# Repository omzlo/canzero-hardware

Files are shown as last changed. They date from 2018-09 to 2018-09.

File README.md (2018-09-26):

# Canzero Hardware

This repository contains the design files and schematics of the Omzlo CANZERO, an Arduino-compatible CAN-bus node.

See: http://omzlo.com/canzero

This work is licensed under the [Creative Commons Attribution-ShareAlike 4.0 International Public License][1].

[1]: https://creativecommons.org/licenses/by-sa/4.0/

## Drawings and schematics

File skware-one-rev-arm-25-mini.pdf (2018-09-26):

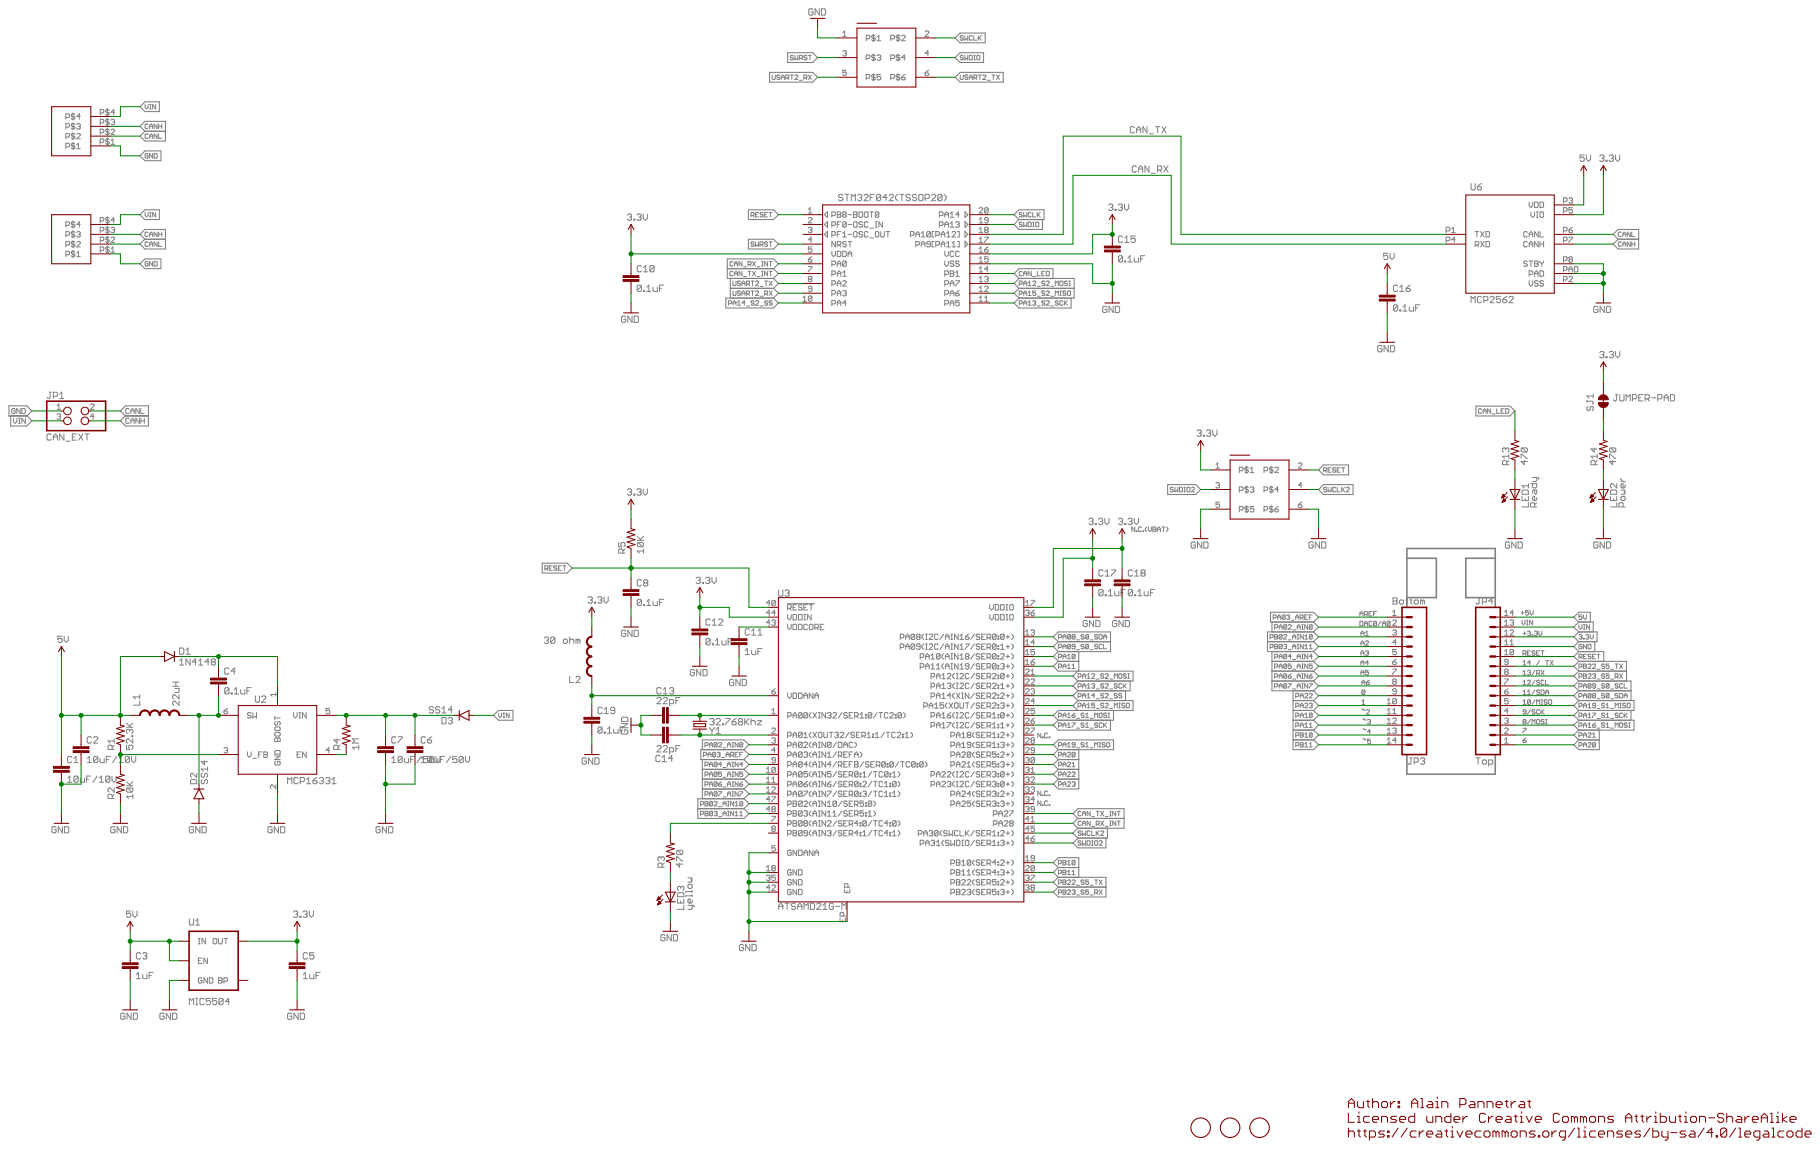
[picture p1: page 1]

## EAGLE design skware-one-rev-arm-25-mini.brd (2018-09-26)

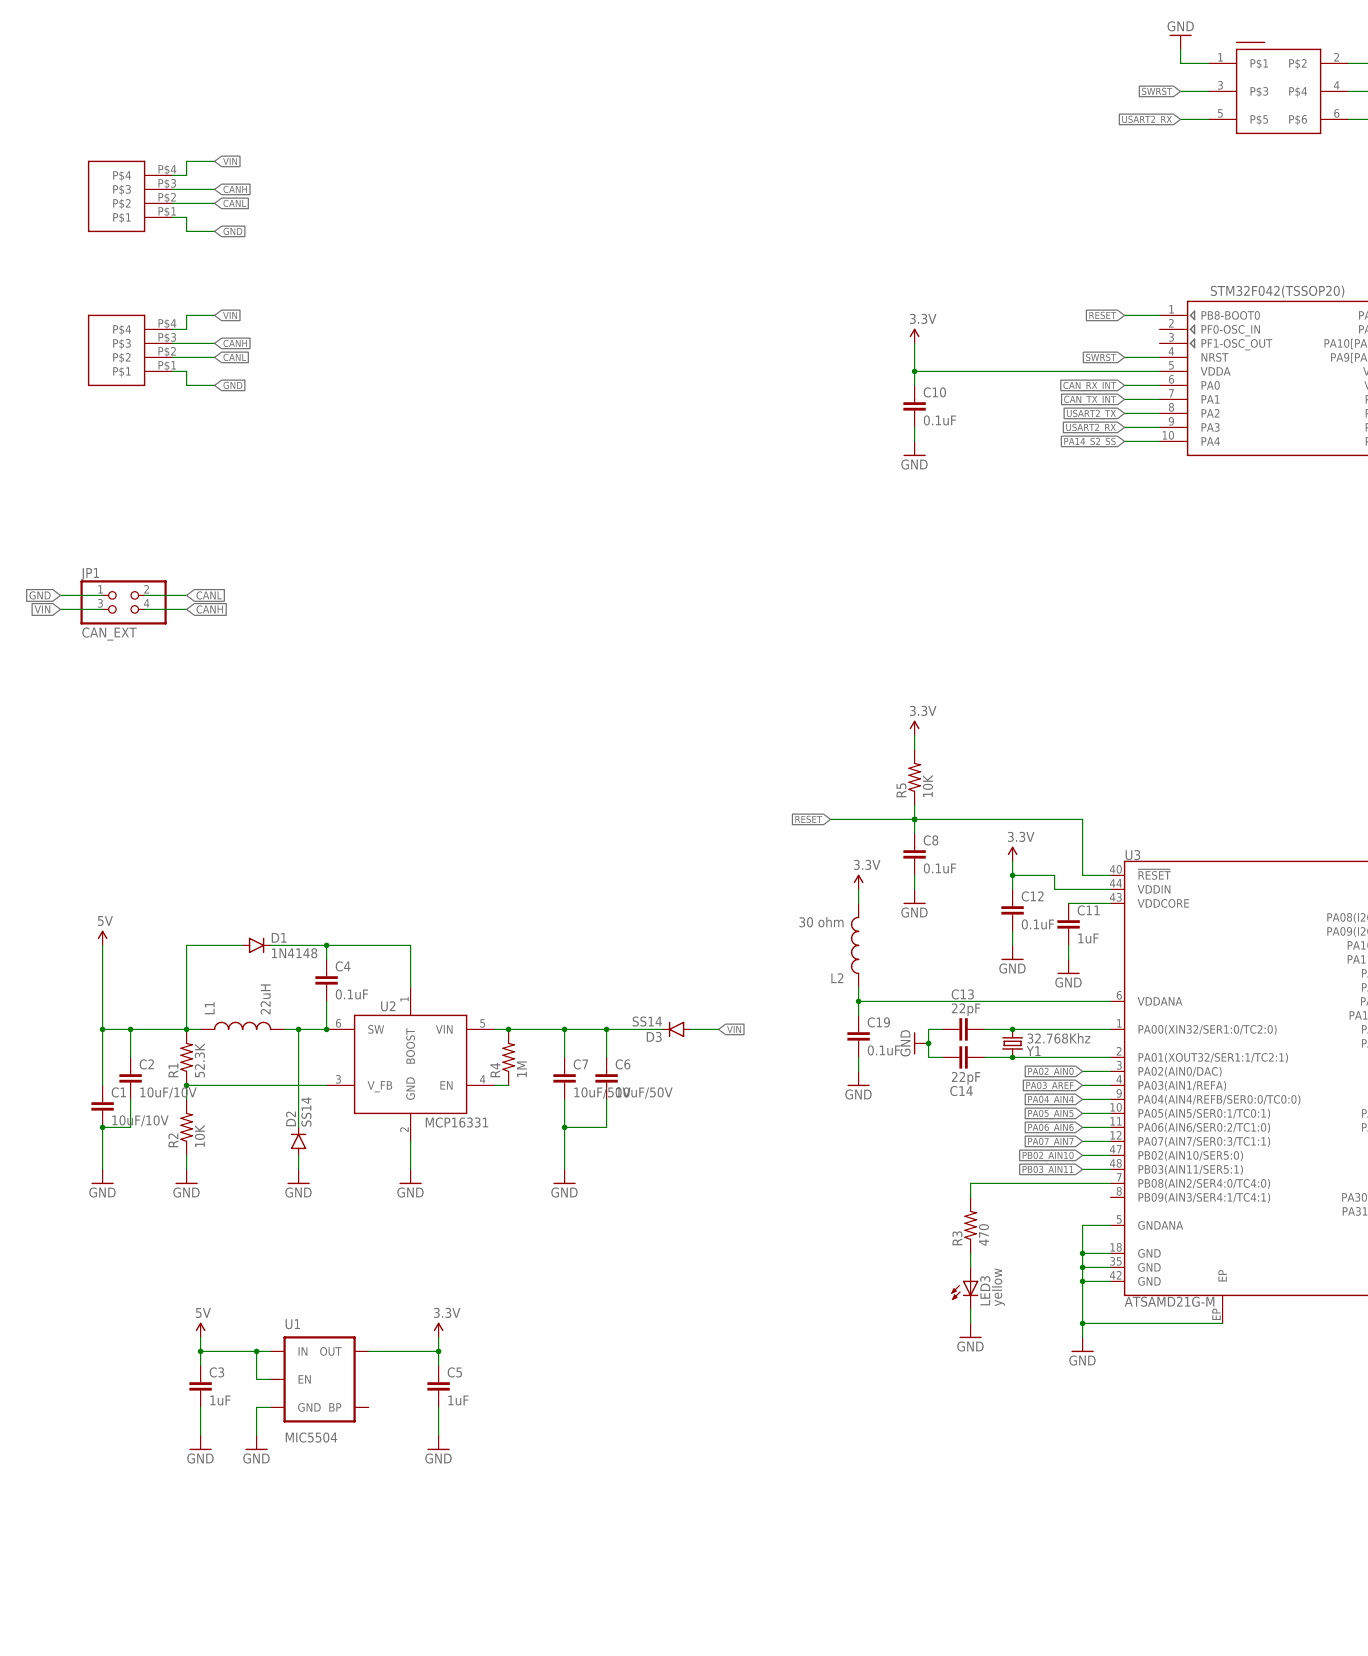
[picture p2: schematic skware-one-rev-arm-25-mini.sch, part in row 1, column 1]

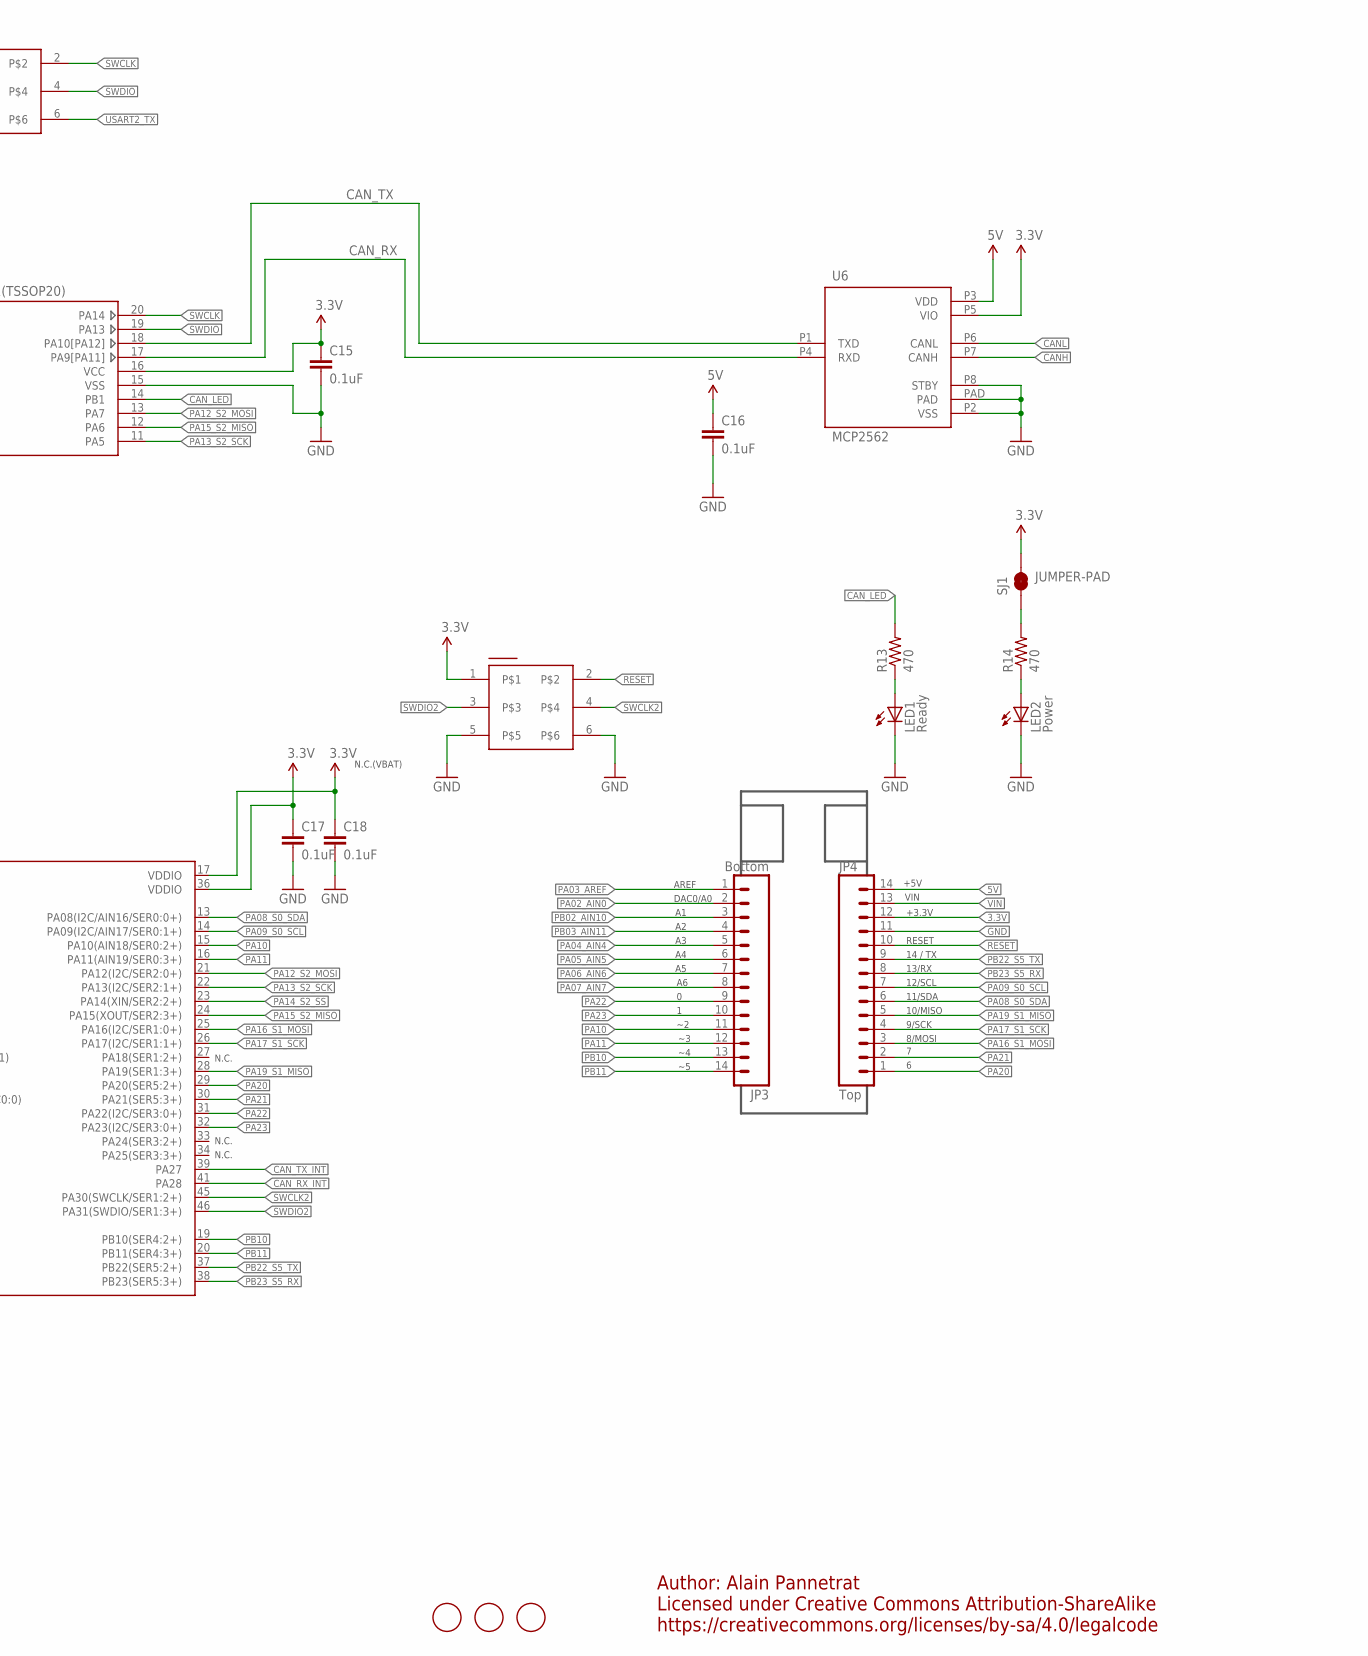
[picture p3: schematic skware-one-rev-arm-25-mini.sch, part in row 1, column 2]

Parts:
C1, C2: 10uF/10V; 0805
C3, C5, C11: 1uF; 0805
C4, C8, C10, C12, C15, C16, C17, C18, C19: 0.1uF; 0603-CAP
C6, C7: 10uF/50V; 1206
C13, C14: 22pF; 0805
D1: 1N4148; SOD-323
D2, D3: SS14; SMA-DIODE_ALT
JP1: CAN_EXT; 2X02
JP3: Bottom; 1X14
JP4: Top; 1X14
L1: 22uH; SRN6045
L2: 30 ohm; 0603
LED1: Ready; SML0805
LED2: Power; SML0805
LED3: yellow; SML0805
R1: 52.3K; 0805
R2, R5: 10K; 0805
R3, R13, R14: 470; 0603-RES
R4: 1M; 0805
SJ1: JUMPER-PAD; PAD-JUMPER-2-NC_BY_TRACE_YES_SILK
U1: MIC5504; SOT23-5
U2: MCP16331; SOT23-6
U3: ATSAMD21G-M; QFN-48
U4: STM32F042(TSSOP20); TSSOP20
U6: MCP2562; DFN3X3
U$1, U$3: M04-PLUG-3.5
U$4, U$5: 3X2-SMT-PROG; 2X3-SMT-HEAD
U$6, U$7, U$8: FIDUCIAL; FIDUCIAL_1MM
Y1: 32.768Khz; CRYSTAL-SMD-3.2X1.5MM

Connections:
3.3V: C5.1, C10.1, C12.1, C15.1, C17.1, C18.1, JP4.12, L2.2, R5.2, SJ1.2, U1.5 (OUT), U3.17 (VDDIO), U3.36 (VDDIO), U3.44 (VDDIN), U4.5 (VDDA), U4.16 (VCC), U6.P5 (VIO), U$4.1
5V: C1.1, C2.1, C3.1, C16.1, D1.A, JP4.14, L1.1, R1.2, U1.1 (IN), U1.3 (EN), U6.P3 (VDD)
A1: R3.2, U3.7 (PB08(AIN2/SER4:0/TC4:0))
CANH: JP1.4, U6.P7 (CANH), U$1.P$3, U$3.P$3
CANL: JP1.2, U6.P6 (CANL), U$1.P$2, U$3.P$2
CAN_LED: R13.2, U4.14 (PB1)
CAN_RX: U4.17 (PA9[PA11]), U6.P4 (RXD)
CAN_RX_INT: U3.41 (PA28), U4.6 (PA0)
CAN_TX: U4.18 (PA10[PA12]), U6.P1 (TXD)
CAN_TX_INT: U3.39 (PA27), U4.7 (PA1)
GND: C1.2, C2.2, C3.2, C5.2, C6.2, C7.2, C8.2, C10.2, C11.2, C12.2, C13.1, C14.1, C15.2, C16.2, C17.2, C18.2, C19.2, D2.A, JP1.1, JP4.11, LED1.C, LED2.C, LED3.C, R2.1, U1.2 (GND), U2.2 (GND), U3.5 (GNDANA), U3.18 (GND), U3.35 (GND), U3.42 (GND), U3.EP, U4.15 (VSS), U6.P2 (VSS), U6.P8 (STBY), U6.PAD, U$1.P$1, U$3.P$1, U$4.5, U$4.6, U$5.1
unnamed: R4.1, U2.4 (EN)
unnamed: C11.1, U3.43 (VDDCORE)
unnamed: C13.2, U3.1 (PA00(XIN32/SER1:0/TC2:0)), Y1.P$2 (2)
unnamed: C14.2, U3.2 (PA01(XOUT32/SER1:1/TC2:1)), Y1.P$1 (1)
unnamed: C19.1, L2.1, U3.6 (VDDANA)
unnamed: R14.2, SJ1.1
unnamed: LED2.A, R14.1
unnamed: C6.1, C7.1, D3.C, R4.2, U2.5 (VIN)
unnamed: LED3.A, R3.1
unnamed: LED1.A, R13.1
unnamed: R1.1, R2.2, U2.3 (V_FB)
unnamed: C4.2, D2.C, L1.2, U2.6 (SW)
unnamed: C4.1, D1.C, U2.1 (BOOST)
PA02_AIN0: JP3.2, U3.3 (PA02(AIN0/DAC))
PA03_AREF: JP3.1, U3.4 (PA03(AIN1/REFA))
PA04_AIN4: JP3.5, U3.9 (PA04(AIN4/REFB/SER0:0/TC0:0))
PA05_AIN5: JP3.6, U3.10 (PA05(AIN5/SER0:1/TC0:1))
PA06_AIN6: JP3.7, U3.11 (PA06(AIN6/SER0:2/TC1:0))
PA07_AIN7: JP3.8, U3.12 (PA07(AIN7/SER0:3/TC1:1))
PA08_S0_SDA: JP4.6, U3.13 (PA08(I2C/AIN16/SER0:0+))
PA09_S0_SCL: JP4.7, U3.14 (PA09(I2C/AIN17/SER0:1+))
PA10: JP3.11, U3.15 (PA10(AIN18/SER0:2+))
PA11: JP3.12, U3.16 (PA11(AIN19/SER0:3+))
PA12_S2_MOSI: U3.21 (PA12(I2C/SER2:0+)), U4.13 (PA7)
PA13_S2_SCK: U3.22 (PA13(I2C/SER2:1+)), U4.11 (PA5)
PA14_S2_SS: U3.23 (PA14(XIN/SER2:2+)), U4.10 (PA4)
PA15_S2_MISO: U3.24 (PA15(XOUT/SER2:3+)), U4.12 (PA6)
PA16_S1_MOSI: JP4.3, U3.25 (PA16(I2C/SER1:0+))
PA17_S1_SCK: JP4.4, U3.26 (PA17(I2C/SER1:1+))
PA19_S1_MISO: JP4.5, U3.28 (PA19(SER1:3+))
PA20: JP4.1, U3.29 (PA20(SER5:2+))
PA21: JP4.2, U3.30 (PA21(SER5:3+))
PA22: JP3.9, U3.31 (PA22(I2C/SER3:0+))
PA23: JP3.10, U3.32 (PA23(I2C/SER3:0+))
PB02_AIN10: JP3.3, U3.47 (PB02(AIN10/SER5:0))
PB03_AIN11: JP3.4, U3.48 (PB03(AIN11/SER5:1))
PB10: JP3.13, U3.19 (PB10(SER4:2+))
PB11: JP3.14, U3.20 (PB11(SER4:3+))
PB22_S5_TX: JP4.9, U3.37 (PB22(SER5:2+))
PB23_S5_RX: JP4.8, U3.38 (PB23(SER5:3+))
RESET: C8.1, JP4.10, R5.1, U3.40 (!RESET!), U4.1 (PB8-BOOT0), U$4.2
SWCLK: U4.20 (PA14), U$5.2
SWCLK2: U3.45 (PA30(SWCLK/SER1:2+)), U$4.4
SWDIO: U4.19 (PA13), U$5.4
SWDIO2: U3.46 (PA31(SWDIO/SER1:3+)), U$4.3
SWRST: U4.4 (NRST), U$5.3
USART2_RX: U4.9 (PA3), U$5.5
USART2_TX: U4.8 (PA2), U$5.6
VIN: D3.A, JP1.3, JP4.13, U$1.P$4, U$3.P$4

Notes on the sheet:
N.C.(VBAT)
AREF
DAC0/A0
+5V
VIN
+3.3V
RESET
14 / TX
13/RX
12/SCL
11/SDA
10/MISO
9/SCK
8/MOSI
N.C.
Author: Alain Pannetrat Licensed under Creative Commons Attribution-ShareAlike https://creativecommons.org/licenses/by-sa/4.0/legalcode

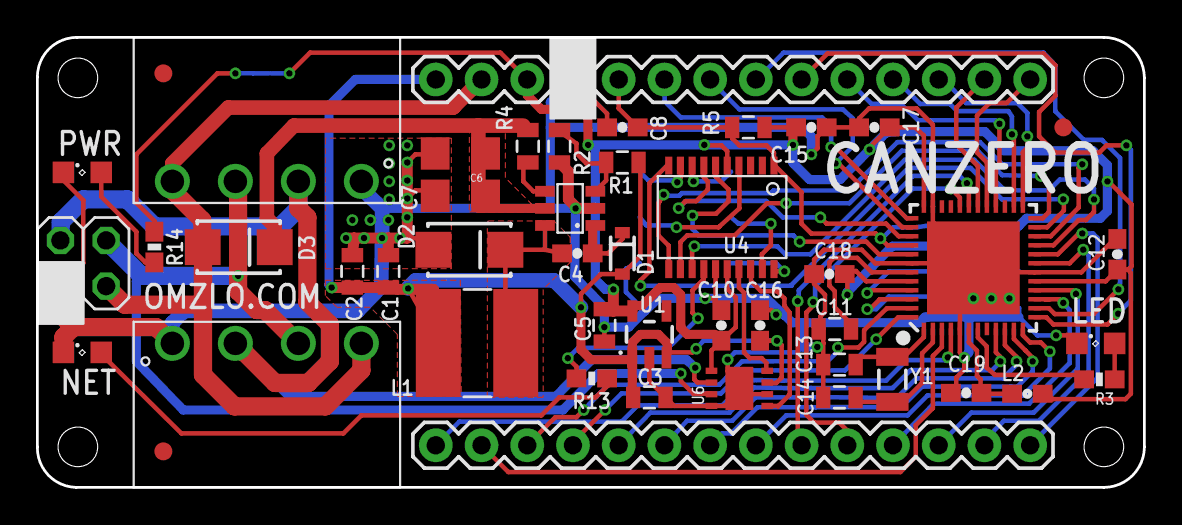
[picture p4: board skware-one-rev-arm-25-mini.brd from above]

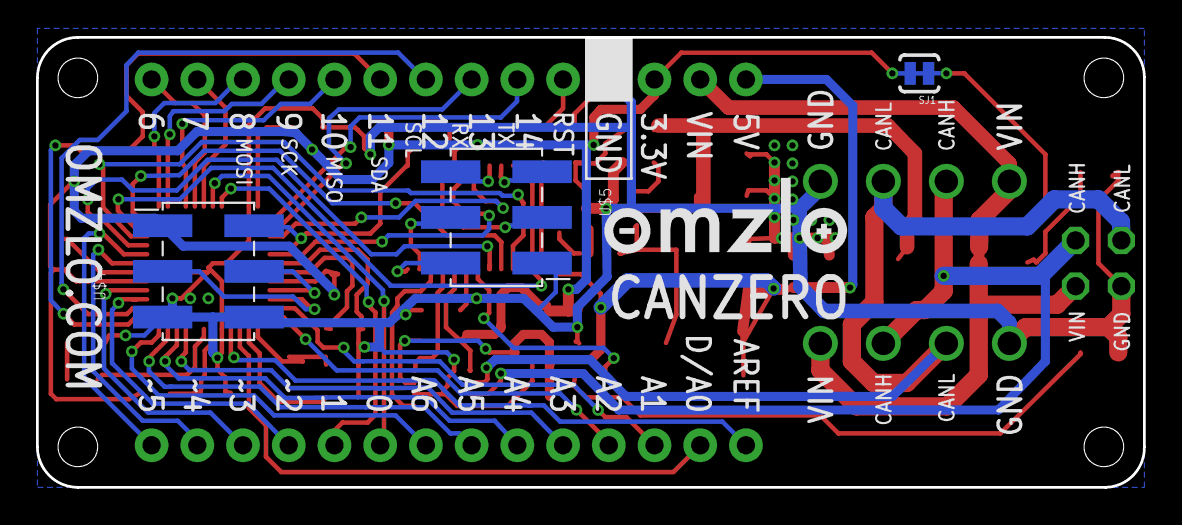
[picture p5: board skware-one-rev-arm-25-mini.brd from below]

Board: 2 copper layers, 61.5 x 25.0 mm, 51 parts (4 on the bottom side), 60 nets.

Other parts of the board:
U$2: OMZLO-0.5

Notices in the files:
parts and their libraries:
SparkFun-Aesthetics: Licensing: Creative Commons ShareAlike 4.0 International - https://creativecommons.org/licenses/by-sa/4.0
